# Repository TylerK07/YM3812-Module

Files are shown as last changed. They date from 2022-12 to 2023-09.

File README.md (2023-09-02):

# YM3812-Module
This code repository parallels a series of articles about a YM3812 module written on thingsmadesimple.com

With each new article, the functionality of the module will grow, and the associated code and schematics will be available here.

<hr/>

## Current Articles

### <a href='https://www.thingsmadesimple.com/2022/11/28/ym3812-part-1-register-basics/'>YM3812 Part 1: Register Basics</a>
Focuses on FM Synthesis basics, the YM3812's register map and electrically controlling the chip's pins.

### <a href='https://thingsmadesimple.com/2023/01/02/ym3812-part-2-face-reveal/'>YM3812 Part 2: FACE Reveal</a>
Introduces a basic implementation of the YM3812 circuit controlled by an AVR128DA28 microcontroller that we will build on in future articles. Think of it as a "Hello World" starting point that ensure the circuit works and that we can upload code to the microcontroller.

### <a href='https://www.thingsmadesimple.com/2023/01/21/ym3812-part-3-behind-the-code/'>YM3812 Part 3: Behind the Code</a>
Walks through the implementation of the YM3812 class used in Part 2 and describes how each of the register manipulation functions work.

### <a href='https://www.thingsmadesimple.com/2023/02/11/ym3812-part-4-midi-journey/'>YM3812 Part 4: MIDI Journey</a>
Adds a MIDI input to our schematic, and discusses how to translate MIDI note numbers into frequencies the YM3812 understands

### <a href='https://www.thingsmadesimple.com/2023/03/05/ym3812-part-5-midi-polyphony/'>YM3812 Part 5: MIDI Polyphony</a>
Adds Polyphony to our breadboard module, walking through a couple of algorithms in the process.

### <a href='https://www.thingsmadesimple.com/2023/04/29/ym3812-part-6-patches/'>YM3812 Part 6: Patches</a>
Revise the YM3812 class implementation to support more generic instrument definition

### <a href='https://www.thingsmadesimple.com/2023/05/13/ym3812-part-7-percussive-maintenance/'>YM3812 Part 7: Percussive Maintenance</a>
Add General MIDI drum support by linking different drum sounds to different notes on the keyboard

### <a href='https://www.thingsmadesimple.com/2023/05/30/ym3812-part-8-velocity-sensitivity/'>YM3812 Part 8: Velocity Sensitivity</a>
Add touch sensitivity to the module by selectively scaling the right operator levels

### <a href='https://www.thingsmadesimple.com/2023/07/28/ym3812-part-9-synth-card/'>YM3812 Part 9: SynthCard</a>
Turn that breadboard into a business card sized PCB!

### <a href='https://www.thingsmadesimple.com/2023/09/02/ym3812-part-10-pitch-bend/'>YM3812 Part 10: Pitch Bend</a>
Add pitch bend capabilities and shred on a YM3812

<hr/>

## Article Backlog:

### YM3812 Part ?: OPL2 in STEREO!
Add another YM3812 chip and some stereo effects for panning and detuning

### YM3812 Part ?: Adding a menu to swap patches
Add a TFT Screen and a Rotary Encoder so we can adjust patch assignments to MIDI channels

### YM3812 Part ?: Adjust Patch Properties
Add buttons and a menu system that lets us adjust patch settings individually

### YM3812 Part ?: Visualizing 2-OP envelopes
Add a graphical visualization that helps us interpret patch settings

### YM3812 Part ?: Virtual 4-OP Voices
Add support for virtual four-operator voices

and more...

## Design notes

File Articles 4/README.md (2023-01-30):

### <a href=''>YM3812 Part 4: MIDI Journey</a>
This article introduces the circuitry and functionality necessary to implement MIDI on the YM3812 module. This article especially focuses on translating note frequencies between MIDI note codes and the block / F-Number properties used by the YM3812. To demonstrate how the translation function and basic MIDI handlers work, this code implements a monophonic midi algorithm that plays all incoming notes on channel zero of the YM3812.

<hr/>

### Schematic
The schematic folder includes adds MIDI functionality to the basic schematic used in articles 1-3.
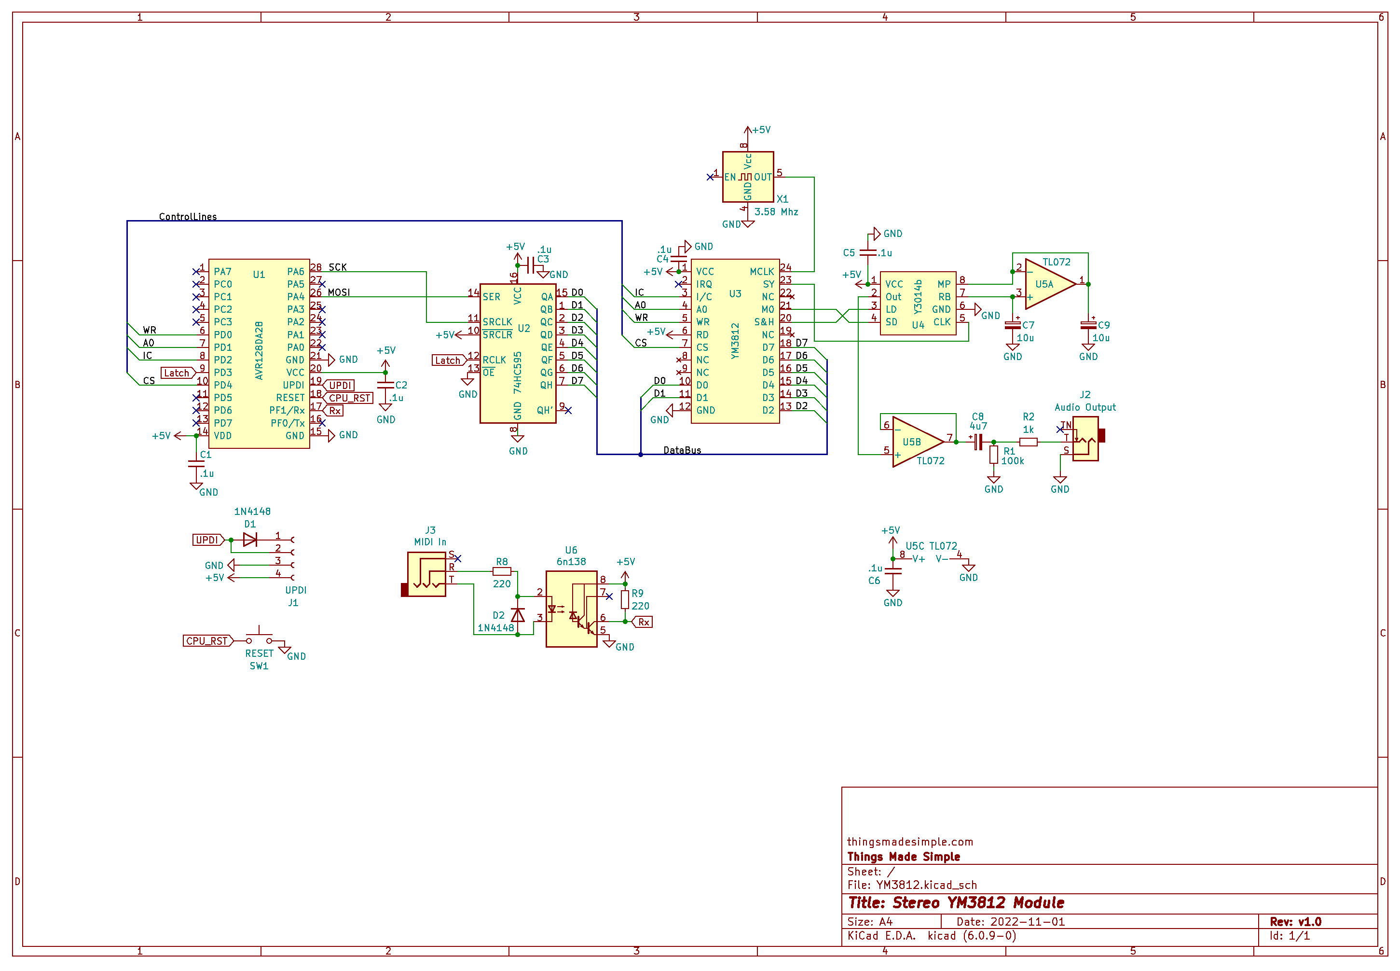
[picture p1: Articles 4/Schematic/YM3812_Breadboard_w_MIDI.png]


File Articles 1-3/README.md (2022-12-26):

# Articles 1-3
The first three articles provide an introduction to the YM3812 sound processor as well as the basic schematic and code necessary to get things up and running.

<hr/>

## Current Articles

### <a href='https://www.thingsmadesimple.com/2022/11/28/ym3812-part-1-register-basics/'>YM3812 Part 1: Register Basics</a>
Focuses on FM Synthesis basics, the YM3812's register map and electrically controlling the chip's pins. You can find the register map and timing diagrams below (or in the Documentation folder).

### YM3812 Part 2: FACE Reveal
Introduces a basic implementation of the YM3812 circuit controlled by an AVR128DA28 microcontroller that we will build upon in future articles. Think of it as a "Hello World"-like starting point that ensures the circuit works and that we can upload code into the microcontroller. We cover the function of each IC, the schematic, and after building it on breadboard, how to program it through the Arduino IDE.

### YM3812 Part 3: Getting Classy (Coming Soon)
Walks through the implementation of the YM3812 class and other code that we used (but didn't discuss) in the second article. We cover the sendData and reset functions as well as the bit manipulation function that inserts sub-8-bit numbers into 8-bit registers. Then with these building blocks in place, we implement the register manipulation functions for all of the global, channel and operator level settings.

<hr/>

## Documentation:
The documentation folder contains a couple of helpful charts:
### Register Map
The register map shows where each setting is located on the chip.
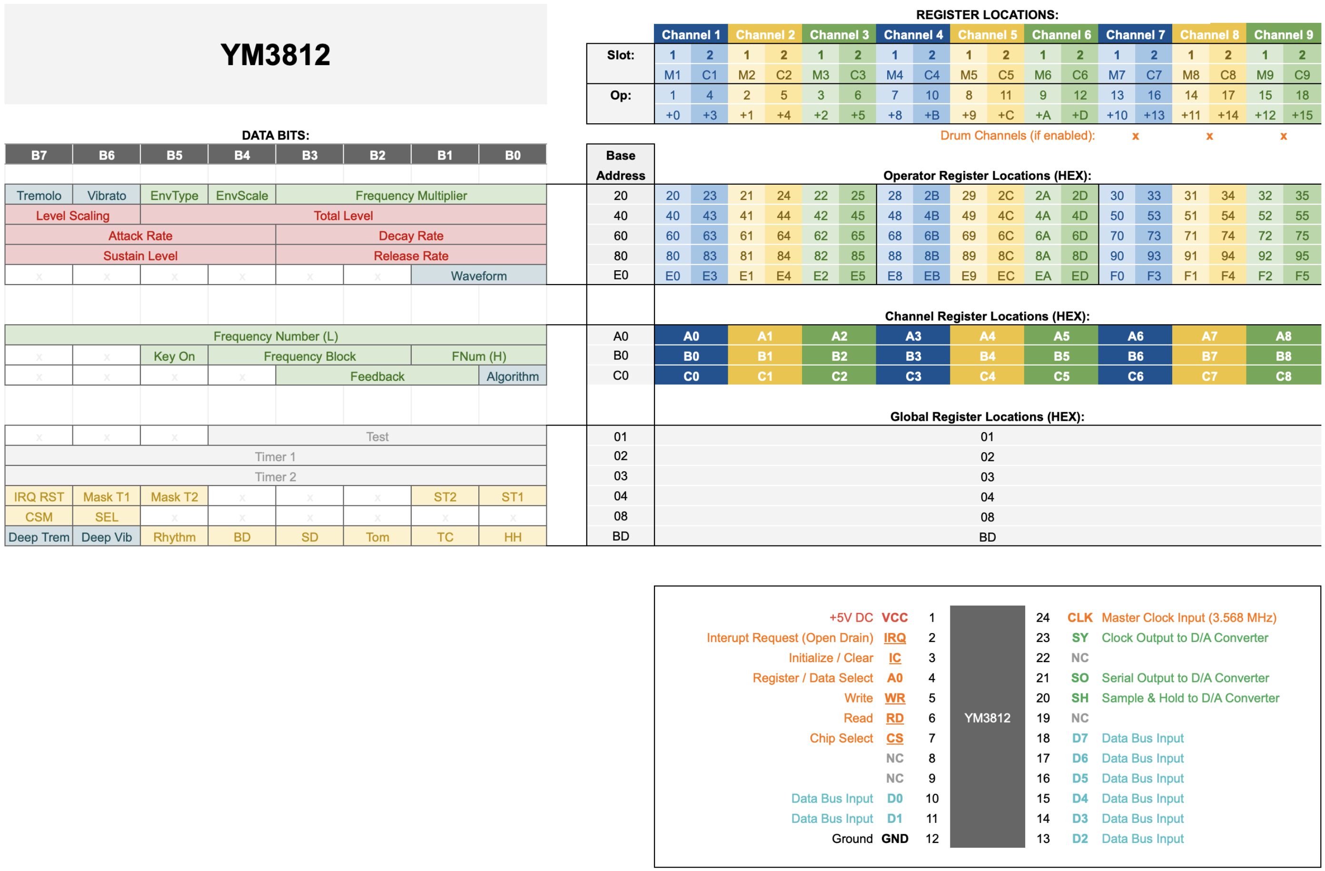
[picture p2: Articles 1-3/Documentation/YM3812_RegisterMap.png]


### Timing Chart
The Timing Chart visually describes the order of events used to update a register on the YM3812.
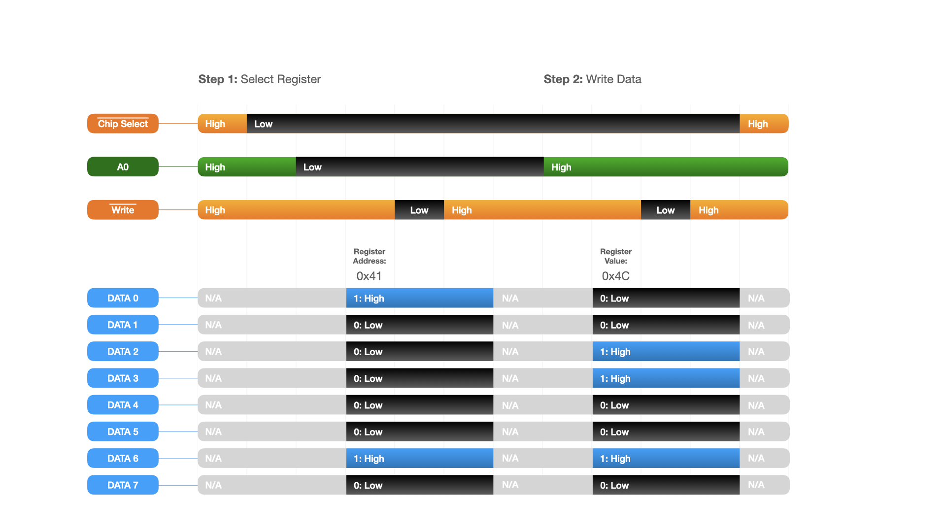
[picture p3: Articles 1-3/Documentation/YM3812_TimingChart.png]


### Schematic
The schematic folder includes a basic schematic used to get the YM3812 up and running.
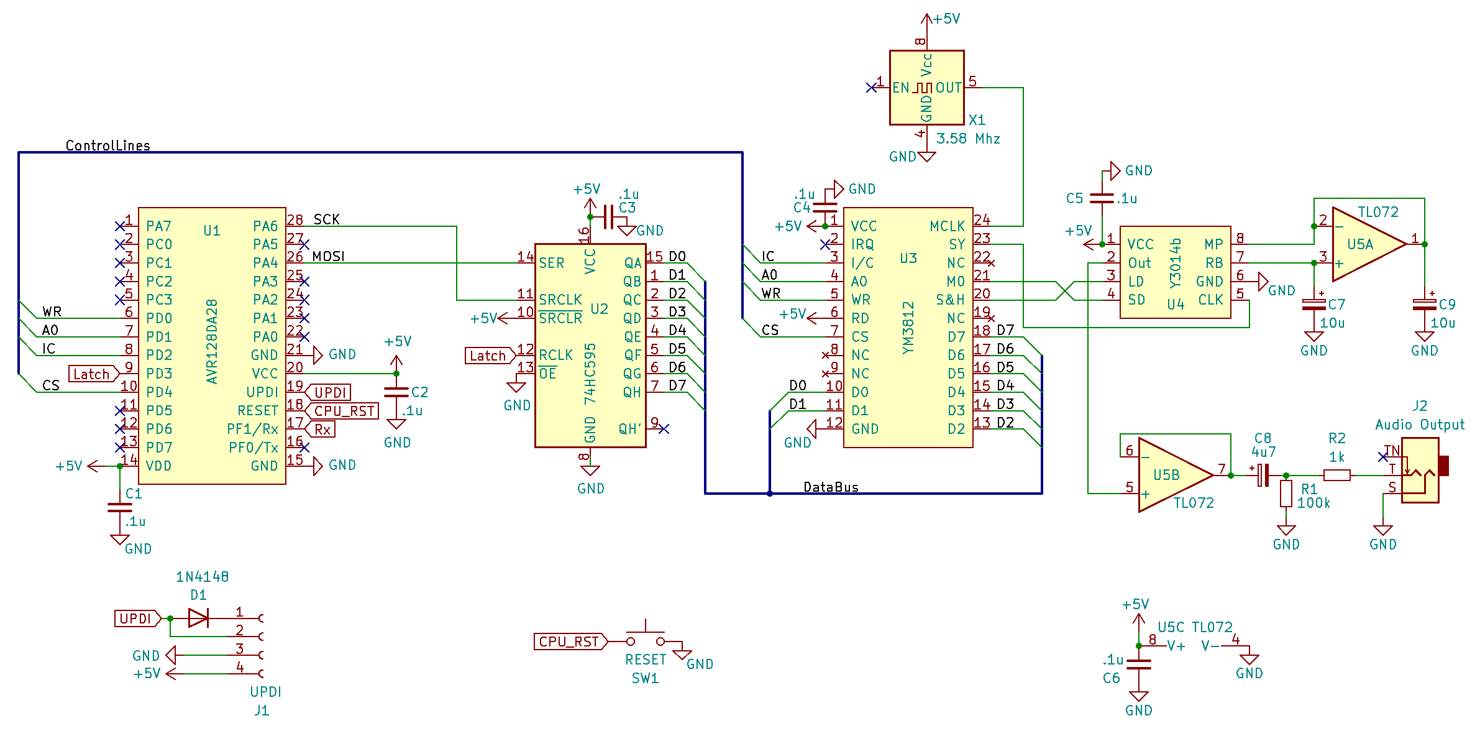
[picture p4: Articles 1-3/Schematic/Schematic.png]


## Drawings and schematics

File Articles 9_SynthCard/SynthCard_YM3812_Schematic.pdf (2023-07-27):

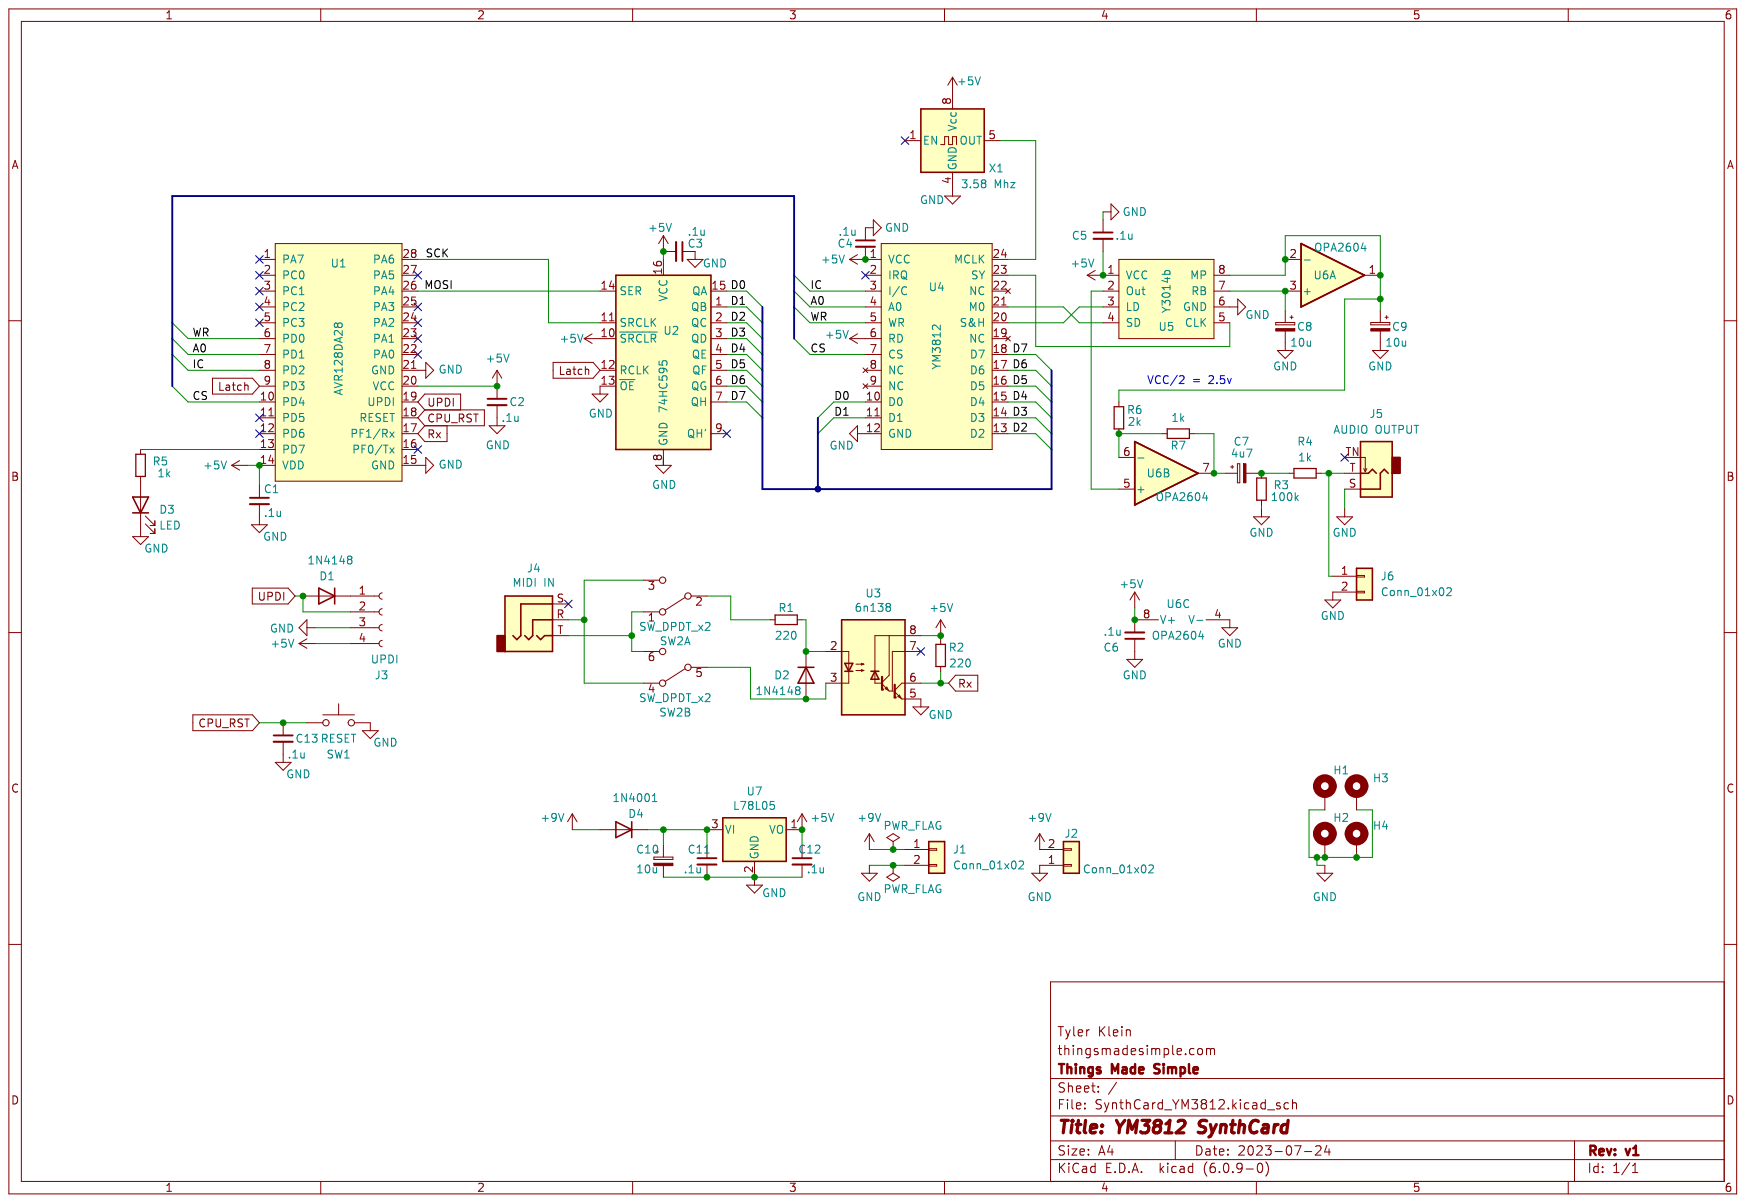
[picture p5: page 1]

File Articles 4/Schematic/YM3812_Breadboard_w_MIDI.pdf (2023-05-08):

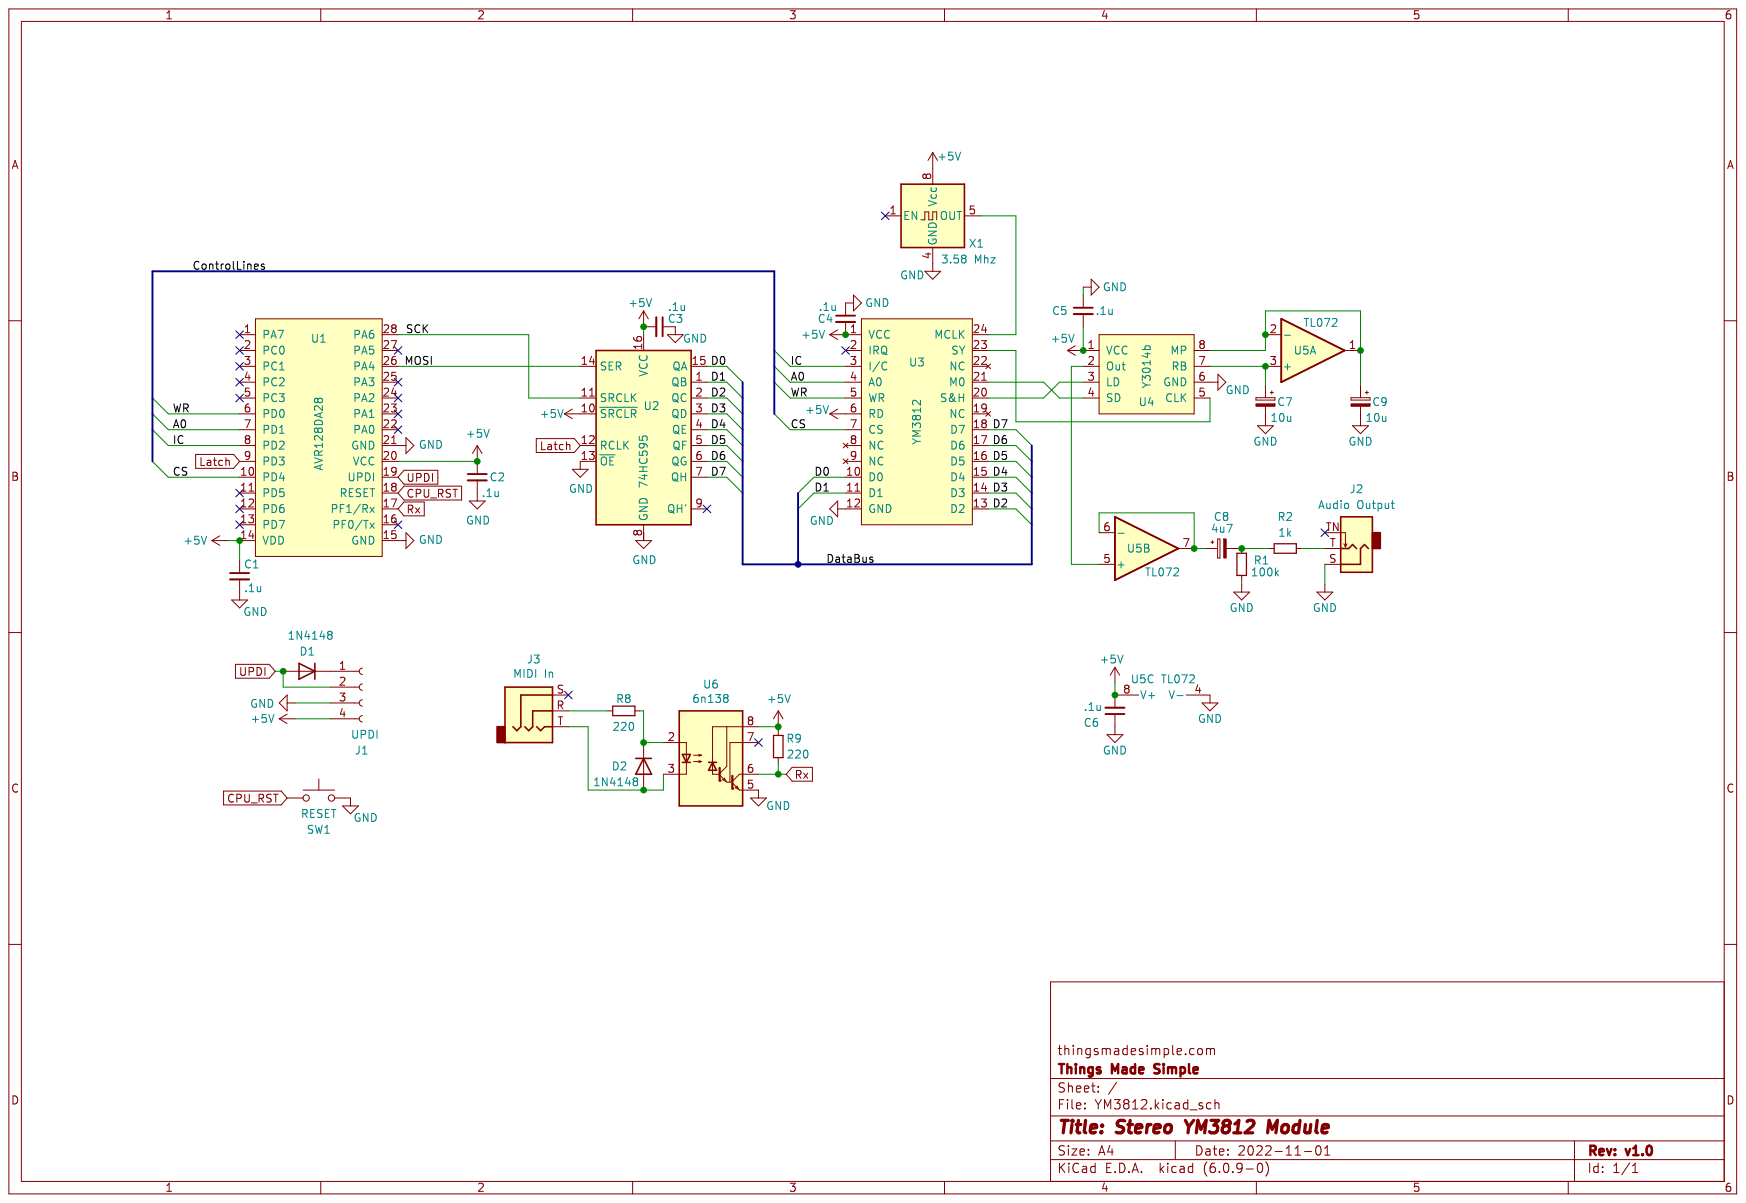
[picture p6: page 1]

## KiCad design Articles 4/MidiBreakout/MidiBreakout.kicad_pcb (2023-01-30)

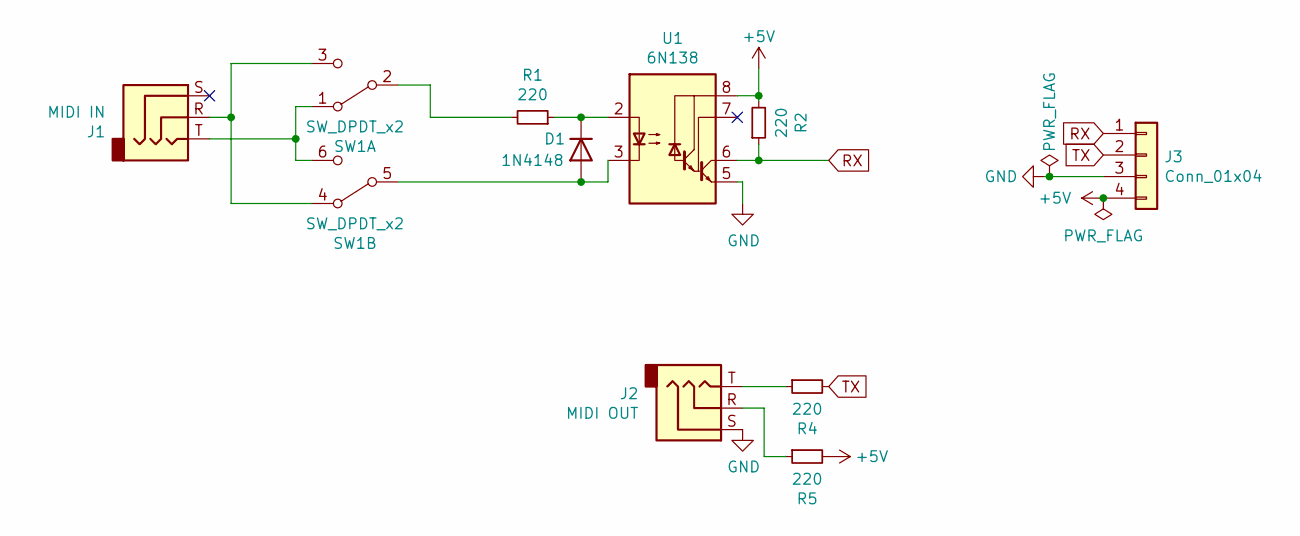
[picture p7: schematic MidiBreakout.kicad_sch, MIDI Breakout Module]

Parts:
D1: 1N4148; D_DO-35_SOD27_P7.62mm_Horizontal
J1: MIDI IN; PJ392_3.5MM_Vertical
J2: MIDI OUT; PJ392_3.5MM_Vertical
J3: Conn_01x04; PinHeader_1x04_P2.54mm_Vertical
R1, R2, R4, R5: 220; R_Axial_DIN0207_L6.3mm_D2.5mm_P7.62mm_Horizontal
SW1: SW_DPDT_x2; SW_E-Switch_EG1271_DPDT
U1: 6N138; DIP-8_W7.62mm_Socket_LongPads

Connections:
+5V: J3.4, R2.2, R5.2, U1.8 (VCC)
GND: J2.S, J3.3, U1.5 (GND)
unnamed: D1.1 (K), R1.1, U1.2 (C1)
unnamed: D1.2 (A), SW1.5 (B), U1.3 (C2)
unnamed: J1.R, SW1.3 (C), SW1.4 (A)
unnamed: J1.T, SW1.1 (A), SW1.6 (C)
unnamed: J2.R, R5.1
unnamed: J2.T, R4.1
unnamed: R1.2, SW1.2 (B)
RX: J3.1, R2.1, U1.6 (VO2)
TX: J3.2, R4.2

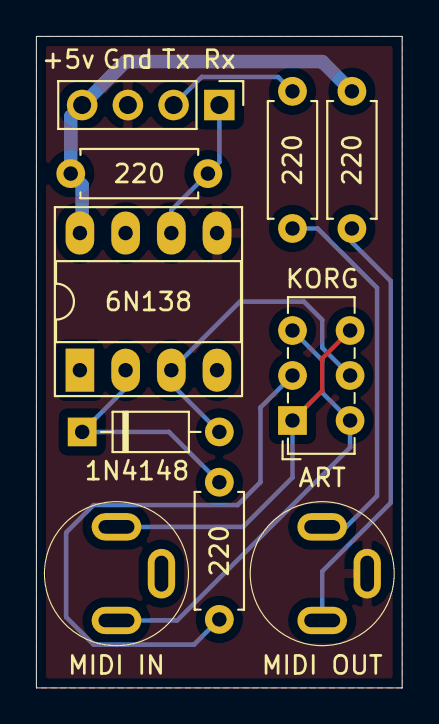
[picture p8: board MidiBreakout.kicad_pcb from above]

Board: 2 copper layers, 20.3 x 36.2 mm, 10 parts (0 on the bottom side), 11 nets.

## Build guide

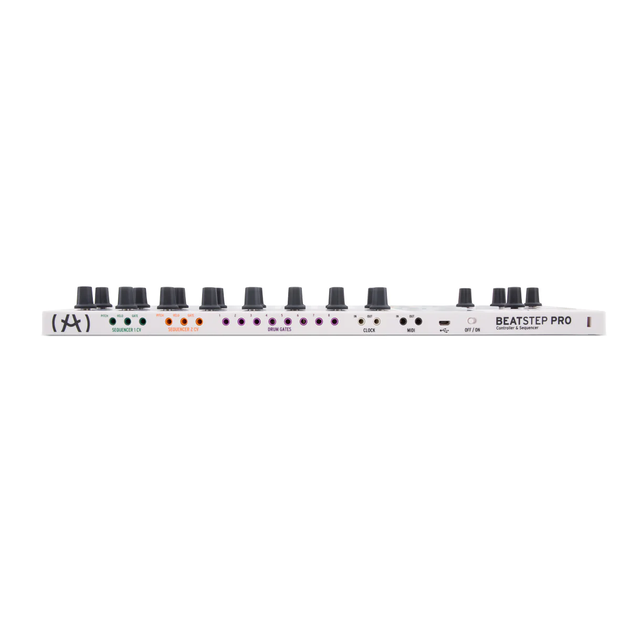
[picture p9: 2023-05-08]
Articles 4/Schematic/BeatStepPro_back_1200x1200.png

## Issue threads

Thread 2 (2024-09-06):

Feedback implementation in OPL chips

tisnik, 2024-09-06:
Hi @TylerK07,

first of all, thank you very much making articles about OPL chips. My son got very interested in it and now we are making our own OPL2-based synth (RP2040+OPL2 connected via SPI).

I'm not sure how you made the following animation, especially how feedback is passed back into operator input:
https://www.thingsmadesimple.com/wp-content/uploads/2022/11/SinToSawToNoise.gif

My code does not produce similar output - the sin is slowly transformed into sawtooth wave, but then 'chaotic' part emerges very quickly, but in our case the transformation is perfectly smooth. I must miss something (also tried to decipher ols3.c from DOSBox, but it's focused on low level HW implementation):

```python
n = 5000

x = np.zeros((n,))
y = np.zeros((n,))

t = 0
f = 0.002
feedback_strength = 1.95
output=0

for i in range(0, n):
    modulator = sin(t*f + output)
    carrier = sin(modulator * feedback_strength)

    x[i] = i
    y[i] = carrier
    output = carrier

    t += 1

plt.plot(x, y, "-", markersize=1)
```

TylerK07, 2024-09-07:
Hey @tisnik, so glad you and your son are diving into these chips!

I actually made the animation by plotting out each point in a google spreadsheet, screen capturing a graph, and then merging them together into an animation.

The formula was something like:
next_output = SIN( current_time + beta * previous_output )

I used time increments of 0.1

When beta is 0, you get a perfect sine wave
When beta is 1, you get a sawtooth wave
You start to see distortion between 1 and 1.5
When you get to 3, it's just total chaos

Here is a link to the spreadsheet. You'll have to make a copy to adjust the value of Beta: https://docs.google.com/spreadsheets/d/1CMSLUd1Nq_zkhkP9MG4-4xsd79PoY94vUL5p5mzv1L8/edit?usp=sharing

Good luck!

tisnik, 2024-09-07:
Hi @TylerK07 ,

thank you very much! With the help of your spreadsheet I figured out what was wrong in the first place - too many values computed :) Like in most equations without feedback, the more values (and the smaller) steps, the graph will be smoother. But when feedback is introduced, there's huge difference between having let's say 100 values in one period or 200 values. Now it's all clear (and it make sense after all). Thank you very much and have a nice day!

Closed 2025-05-16.

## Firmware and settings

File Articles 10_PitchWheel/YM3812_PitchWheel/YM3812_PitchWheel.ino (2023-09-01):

/*
    _____.___.  _____  ________    ______  ____________
    \__  |   | /     \ \_____  \  /  __  \/_   \_____  \
     /   |   |/  \ /  \  _(__  <  >      < |   |/  ____/
     \____   /    Y    \/       \/   --   \|   /       \
     / ______\____|__  /______  /\______  /|___\_______ \
     \/              \/       \/        \/             \/
            ________ __________.____    ________
            \_____  \\______   \    |   \_____  \
            /   |   \|     ___/    |    /  ____/
           /    |    \    |   |    |___/       \
           \_______  /____|   |_______ \_______ \
                   \/                 \/       \/


YM3182 OPL2 EuroRack Module source code designed to run on the AVR128DA28.
Copyright (C) 2022 Tyler Klein

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
--- Description ---
This file contains the code for a simplified breadboard YM3812 circuit,
now with patch functionality. This code pairs with an article and YouTube video 
where we rework the YM3812 class implementation to support patches.


AVR128DA28 Pinout:
                   -------__-------
     Not Connected | PA7      PA6 | SPI Bus Clock 74HC595
     Not Connected | PC0      PA5 | Not Connected
     Not Connected | PC1      PA4 | SPI Bus MOSI 74HC595
     Not Connected | PC2      PA3 | Not Connected
     Not Connected | PC3      PA2 | Not Connected
      YM3812 Write | PD0      PA1 | Not Connected
         YM3812 A0 | PD1      PA0 | Not Connected
         YM3812 IC | PD2      GND | Ground
74HC595 Data Latch | PD3      VCC | +5V
YM3812 Chip Select | PD4     UPDI | UPDI Port
     Not Connected | PD5    RESET | Reset Button
     Not Connected | PD6       RX | MIDI In (Serial2)
     Not Connected | PD7       TX | Not Connected
               +5V | AVCC     GND | Ground
                   ----------------
*/

#include "Arduino.h"
#include "YM3812.h"
#include "YMDefs.h"
#include "instruments.h"
#include <MIDI.h>
#include <SPI.h>


//----------------------------------------- SETUP & INITIALIZATION FUNCTIONS -----------------------------------------//

/*******************************************
 * Sound Processor Definition              *
 *******************************************/

YM3812  PROC_YM3812;                                                           // Instantiate the YM3812 library


/*******************************************
 * Instrument Definitions                  *
 *******************************************/
#define  MAX_INSTRUMENTS   16                                                  // Total MIDI instruments to support (one per midi channel)

uint8_t  inst_patch_index[ MAX_INSTRUMENTS ];                                  // Contains index of the patch used for each midi instrument / channel
PatchArr inst_patch_data[  MAX_INSTRUMENTS ];                                  // Contains one patch per instrument

void loadPatchFromProgMem( byte instIndex, byte patchIndex ){                  // Load patch data from program memory into inst_patch_data array
  for( byte i=0; i<PATCH_SIZE; i++ ){                                          // Loop through instrument data
    inst_patch_data[instIndex][i] = pgm_read_byte_near( patches[patchIndex]+i ); // Copy each byte into ram_data
  }
}

#define  DRUM_CHANNEL      10                                                  // The MIDI channel to use for drums
#define  FIRST_DRUM_NOTE   35                                                  // Conforming to GM patch standard, notes [35-81]

PatchArr drum_patch_data[ NUM_DRUMS ];                                         // Patch data for the drums
uint8_t  drum_patch_index[ NUM_DRUMS ];                                        // Array that translates between drum index and drum patchIndex (allows reassignment)

void loadDrumPatchFromProgMem( byte trackIndex, byte patchIndex ){             // Load a patch from program memory into drum_patach_data
  for( byte i=0; i<PATCH_SIZE; i++ ){                                          // Loop through instrument data
    drum_patch_data[trackIndex][i] = pgm_read_byte_near( patches[patchIndex+NUM_MELODIC] + i ); // Copy each byte into ram_data
  }                                                                            // Worth noting that drum patches are stored after instrument
}                                                                              // patches, hence why we add NUM_PATCHES

uint16_t inst_pitch_bend[ MAX_INSTRUMENTS ];                                    // holds current pitch bend value


/*******************************************
 * MIDI Definition                         *
 *******************************************/

MIDI_CREATE_INSTANCE( HardwareSerial, Serial2, MIDI );                         // Create an instance of MIDI library running on Serial port 2

#define RPNMSB  101                                                            // Command ID for RPN Command's Most Significant Byte
#define RPNLSB  100                                                            // Command ID for RPN Command's Least Significant Byte
#define DATAMSB 6                                                              // Command ID for RPN Value's Most Significant Byte
#define DATALSB 38                                                             // Command ID for RPN Value's Least Significant Byte

uint16_t RPN_command = 0x7F7F;                                                 // Holds the current RPN command while bytes are coming in


void handleNoteOn( byte channel, byte midiNote, byte velocity ){               // Handle MIDI Note On Events
  uint8_t ch = channel - 1;                                                    // Convert to 0-indexed from MIDI's 1-indexed channel nonsense
  uint8_t drumIndex;

  if( DRUM_CHANNEL == channel ){                                               // See if the note being played is on the drum channel
    drumIndex = (midiNote - FIRST_DRUM_NOTE) % NUM_DRUMS;                      // Calculate the index of the drum based on the midi note
    PROC_YM3812.patchNoteOn( drum_patch_data[drumIndex], velocity );           // Play the drum patch
  } else {                                                                     // If not a drum channel
    PROC_YM3812.patchNoteOn( inst_patch_data[ch], midiNote, velocity, inst_pitch_bend[ch]); // Pass the patch information for the channel and note to the YM3812
  }

}

void handleNoteOff( byte channel, byte midiNote, byte velocity ){              // Handle MIDI Note Off Events
  uint8_t ch = channel - 1;                                                    // Convert to 0-indexed from MIDI's 1-indexed channel nonsense
  uint8_t drumIndex;

  if( DRUM_CHANNEL == channel ){                                               // See if the note being played is on the drum channel
    drumIndex = (midiNote - FIRST_DRUM_NOTE) % NUM_DRUMS;                      // Calculate the index of the drum based on the midi note
    PROC_YM3812.patchNoteOff( drum_patch_data[drumIndex] );                    // Turn off the drum patch
  } else {                                                                     // If not a drum channel
    PROC_YM3812.patchNoteOff( inst_patch_data[ch], midiNote );                 // Pass the patch information for the channel and note to the YM3812
  }

}

void handleProgramChange( byte channel, byte patchIndex ){
  uint8_t ch = channel-1;                                                      // Convert to 0-indexed from MIDI's 1-indexed channel nonsense
  inst_patch_index[ch] = patchIndex;                                           // Store the patch index
  loadPatchFromProgMem( ch, inst_patch_index[ch] );                            // Load the patch from progmem into regular memory
}

void handlePitchBend( byte channel, int16_t pitchBend ){
  uint8_t ch = channel-1;                                                      // Convert to 0-indexed from MIDI's 1-indexed channel nonsense
  inst_pitch_bend[ch] = pitchBend + 0x2000;                                    // Shift pitchBend value by 0x2000 so it is always positive (and runs 0 ... 0x3FFF)
  PROC_YM3812.patchPitchBend( inst_patch_data[ch], inst_pitch_bend[ch]);       // Update pitch of any currently playing notes
}

void handleControlChange( byte channel, byte command, byte val ){              // Respond to ControlChange commands so we can pick out RPN commands
  switch( command ){
    case RPNMSB:  RPN_command = (RPN_command & 0x007F) | (val << 7);    break; // Capture the MSB value in bits 7 through 13 of RPN_command
    case RPNLSB:  RPN_command = (RPN_command & 0xFF80) | val;           break; // Capture the LSB value in bits 0 through 6 of RPN_command
    case DATAMSB: if( RPN_command==0 ) PROC_YM3812.setBendRange( val ); break; // Check if command is pitch bend sensitivity and then send value to YM3812 library
    case DATALSB:                                                       break; // LSB sets range to less than a semitone. We can ignore that
  }
}



/*******************************************
 * Primary Setup Function                  *
 *******************************************/

void setup(void) {

  // Initialize Patches
  for( byte i=0; i<MAX_INSTRUMENTS; i++ ){                                     // Load patch data from channel_patches into the
    inst_patch_index[i] = i;                                                   // By default, use a different patch for each midi channel
    loadPatchFromProgMem( i, inst_patch_index[i] );                            // instruments array (inst_patch_data)
    inst_pitch_bend[i] = 0x2000;                                               // Set pitch bend to middle value by default
  }
  for( byte i=0; i<NUM_DRUMS; i++ ){                                           // Loop through all of the drum patches and by default,
    drum_patch_index[i] = i;                                                   // Map each drum to another patch, wrap around if more notes than patches
    loadDrumPatchFromProgMem( i, drum_patch_index[i] );                        // Load the drum patches into memory for each drum track
  }

  PROC_YM3812.reset();

  //MIDI Setup
  MIDI.setHandleNoteOn(  handleNoteOn );                                       // Setup Note-on Handler function
  MIDI.setHandleNoteOff( handleNoteOff );                                      // Setup Note-off Handler function
  MIDI.setHandleProgramChange( handleProgramChange );                          // Setup Program Change Handler function
  MIDI.setHandlePitchBend( handlePitchBend );
  MIDI.setHandleControlChange( handleControlChange );

  MIDI.begin();                                                                // Start listening for incoming MIDI

}



//-------------------------------------------------- LOOP FUNCTIONS --------------------------------------------------//

/*******************************************
 * Loop Function                          *
 *******************************************/

void loop() {                                                                  // Main Loop Function

  while( MIDI.read(0) ){}                                                      // Read all incoming data on all MIDI Channels

}

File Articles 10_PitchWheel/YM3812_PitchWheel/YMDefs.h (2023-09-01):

#ifndef YMDEFS_H
#define YMDEFS_H

/*
     _____.___.  _____  ________    ______  ____________
     \__  |   | /     \ \_____  \  /  __  \/_   \_____  \
      /   |   |/  \ /  \  _(__  <  >      < |   |/  ____/
      \____   /    Y    \/       \/   --   \|   /       \
      / ______\____|__  /______  /\______  /|___\_______ \
      \/              \/       \/        \/             \/
            ________ __________.____    ________
            \_____  \\______   \    |   \_____  \
             /   |   \|     ___/    |    /  ____/
            /    |    \    |   |    |___/       \
            \_______  /____|   |_______ \_______ \
                    \/                 \/       \/
.____    ._______________________    _____ _______________.___.
|    |   |   \______   \______   \  /  _  \\______   \__  |   |
|    |   |   ||    |  _/|       _/ /  /_\  \|       _//   |   |
|    |___|   ||    |   \|    |   \/    |    \    |   \\____   |
|_______ \___||______  /|____|_  /\____|__  /____|_  // ______|
        \/           \/        \/         \/       \/ \/


YM3182 OPL2 LIBRARY source code designed to run on the AVR128DA28.
Copyright (C) 2022 Tyler Klein

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
--- Description: ---
This library wraps Yamaha's YM3812 sound processor with functions that allow for direct
manipulation of the chip's registers so you can build cool things like EuroRack modules.
This file contains all of the general definitions used throughout the YM3812 library.
Some of the functions, data structure and macro definitions are in this file because
I want to be able to create projects with multiple types of sound chips. Since they use
the same general variables, I had to pull the more general things into this file.

*/


/*--------- SET & GET bits with a helper macro! ---------//
Set the bits in an 8-bit variable using a bit mask. The bit mask should be right-aligned
for the number of bits you want to include. The offset argument left shifts the bits into the
right position to insert into the register. For example, if you wanted to update bits 4-6 on
variable "regVal", you would go:

SET_BITS( regVal, 0b00000111, 4, newVal );

To get the bits, mask out the ones you want to keep, and use offset to right-shift them to end.
To retreive the bits we just set above, use:

val = GET_BITS( regVal, 0b01110000, 4 );
*/
#define SET_BITS( regVal, mask, offset, newVal) ((regVal) = ((regVal) & (~((mask)<<(offset)))) | (((newVal) & (mask)) << (offset)))
#define GET_BITS( regVal, mask, shift ) ( ((regVal) & (mask)) >> (shift) )


//---------------- NAMES FOR GENERIC PATCH VALUE OFFSETS ----------------//
// The following definitions outline the function of each index in our patch array.
// Note: These indexes go beyond just the functionality of the YM3812 and have been chosen to support a variety
// of Yamaha sound chips. The compatability matrix is shown for each setting below.

#define PATCH_GEN_SETTINGS    10 // Number of non-operator settings (channel, general, etc.)
#define PATCH_OP_SETTINGS     17 // Number of operator settings
#define PATCH_SIZE            PATCH_GEN_SETTINGS + PATCH_OP_SETTINGS * 4 // Total Patch Size

typedef uint8_t PatchArr[PATCH_SIZE]; // Define the PatchArr type as a uint8_t array

// Instrument Level / Virtual
#define PATCH_PROC_CONF        0 // Specifies the processor and desired processor configuration
#define PATCH_NOTE_NUMBER      1 // Indicates the pitch to use when playing as a drum sound
#define PATCH_PEG_INIT_LEVEL   2 // Initial pitch shift before attack begins (Virtual setting - none of the YM chips have this by default)
#define PATCH_PEG_ATTACK       3 // Pitch Envelope Attack (Virtual setting - none of the YM chips have this by default)
#define PATCH_PEG_RELEASE      4 // Pitch Envelope Release (Virtual setting - none of the YM chips have this by default)
#define PATCH_PEG_REL_LEVEL    5 // Final Release Level (Virtual setting - none of the YM chips have this by default)

// Channel Level
#define PATCH_FEEDBACK         6 // Used by: YM3526 | YM3812 | YMF262 | YM2413 | YM2151 |        | YM2612 |
#define PATCH_ALGORITHM        7 // Used by: YM3526 | YM3812 | YMF262 |        | YM2151 |        | YM2612 |
#define PATCH_TREMOLO_SENS     8 // Used by:        |        |        |        | YM2151 |        | YM2612 | *SN76489
#define PATCH_VIBRATO_SENS     9 // Used by:        |        |        |        | YM2151 |        | YM2612 | *SN76489
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

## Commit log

2022-12-26 Add schematic
2023-01-30 Adding code for Article 4
    [MidiBreakout.kicad_pcb, MidiBreakout.kicad_sch]
2023-01-30 Added png of schematic
2023-05-30 Article 8 Code
    Adding code for article 8 about velocity sensitivity.
2023-07-27 SynthCard
    Add SynthCard documentation
    [SynthCard_YM3812.kicad_sch]
2023-09-01 Added Article 10 Pitch Bend
    This update includes all of the code associated with adding Pitch Bend to the YM3812 module

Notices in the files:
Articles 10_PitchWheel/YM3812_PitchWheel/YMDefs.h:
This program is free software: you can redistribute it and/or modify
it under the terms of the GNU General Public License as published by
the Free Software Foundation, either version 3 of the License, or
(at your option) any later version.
